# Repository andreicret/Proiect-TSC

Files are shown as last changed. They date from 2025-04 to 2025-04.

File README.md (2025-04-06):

# TSC OpenBook Reader - Alexandru-Andrei CRET

## Project Content

+ **Schematic & PCB Design** → Circuit design files (.sch, .brd)

+ **Manufacturing Files** → Gerber files, Bill of Materials (BOM), and Pick & Place files.

+ **3D Model & Mechanical Design** → Complete 3D assembly of the device, including PCB, battery, display, and enclosure.

+ **Renders & Images** → Visual representations of the final device and PCB layout.

+ **Documentation** → In-depth explanation of hardware architecture, component connections, and design choices.

## Device Diagram

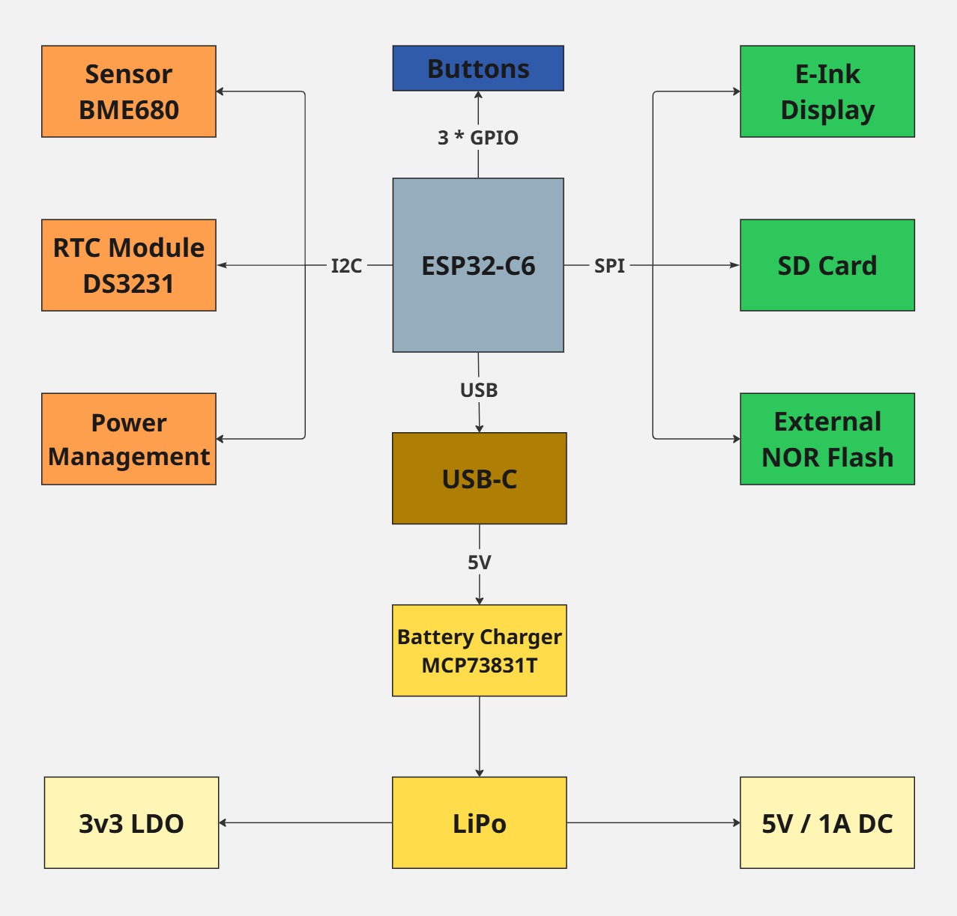
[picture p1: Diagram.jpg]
E-Book Reader Diagram


## Hardware Modules and Components

### ESP32-C6-WROOM-1-N8  (main microcontroller)
- **Key Features:** WiFi 6, Bluetooth 5 LE, RISC-V core
- **Operating Voltage:** 3.3V
- **Communication Interfaces:** SPI, I2C, UART, GPIO

### SD Card Module
- **Interface:** SPI
- **Pin Connections:**
  - `SS_SD` → `IO5`
  - `MOSI` → `IO23`
  - `MISO` → `IO19`
  - `SCK` → `IO18`

### Buttons (User Interface)
- **Interface:** GPIO
- **Pin Connections:**
  - `BUTTON_1` → `IO0` (Used for page turning)
  - `BUTTON_2` → `IO1` (Used for accessing menu options)

### E-Ink Display
- **Interface:** SPI
- **Pin Connections:**
  - `EPD_CS` → `IO15`
  - `EPD_DC` → `IO13`
  - `EPD_RST` → `IO12`
  - `EPD_BUSY` → `IO14`
  - `MOSI`, `SCK` shared with SD card module

### Voltage Regulator (LDO)
- **Purpose:** Converts 5V to 3.3V for powering the ESP32 and other peripherals

### Charging IC (TP4056)
- **Operating Voltage:** 5V via USB-C
- **Function:** Li-Po battery charging and protection

### USB Interface (USB-C Connector)
- **Functionality:** Power and data connection for the device
- **Protection:** ESD protection via TVS diodes

### Li-Po Battery
- **Type:** 3.7V Li-Po
- **Capacity:** 2000mAh

## Communication Interfaces

| **Interface** | **Connected Components** | **ESP32-C6 Pins** |
|---|---|---|
| SPI | E-Ink Display, SD Card | `MOSI` (`IO23`), `MISO` (`IO19`), `SCK` (`IO18`) |
| I2C | (Optional for sensors) | `SDA` (`IO21`), `SCL` (`IO22`) |
| GPIO | Buttons, reset | `IO0`, `IO1` |
| USB | Power and Data (USB-C) | `USB_D+` (`IO14`), `USB_D-` (`IO13`) |

## Estimated Power Consumption

| Component | Average Consumption (mA) |
| :--- | :--- |
| **Typical Total** | **150-250 mA** |
| E-Paper (in refresh) | 20-50 mA |
| SD Card | 30-100 mA |
| DS3231 RTC | 0.2 mA |
| BME688 | 0.8 mA |
| ESP32-C6 (WiFi active) | 80-160 mA |
| External Flash | 10-20 mA |
| ESP32-C6 (idle) | 10 mA |

## Bill of Materials (BOM)

| Component Name | Link | Datasheet |
|---|---|---|
| BD5229G-TR | [Component Search Engine](https://componentsearchengine.com/part-view/BD5229G-TR/ROHM%20Semiconductor) | [Datasheet](https://datasheet.datasheetarchive.com/originals/distributors/Datasheets_SAMA/f2b9741ef86007909f138d561a359946.pdf) |
| ESP32 WROVER 0805 Capacitor | [Mouser](https://ro.mouser.com/ProductDetail/KYOCERA-AVX/SD0805S020S1R0?qs=jCA%252BPfw4LHbpkAoSnwrdjw%3D%3D) | [Datasheet](https://ro.mouser.com/datasheet/2/40/schottky-3165252.pdf) |
| ESP32 WROVER MCP73831 Power Management | [Mouser](https://eu.mouser.com/ProductDetail/Microchip-Technology/MCP73831T-2ACI-OT?qs=yUQqVecv4qvbBQBGbHx0Mw%3D%3D) | [Datasheet](https://eu.mouser.com/datasheet/2/268/MCP73831_Family_Data_Sheet_DS20001984H-3441711.pdf) |
| PGB1010603MR Inductor | [SnapMagic](https://www.snapeda.com/parts/PGB1010603MR/Littelfuse/view-part/?ref=eda) | [Datasheet](https://www.snapeda.com/parts/PGB1010603MR/Littelfuse%20Inc./datasheet/) |
| USBLC6-2SC6Y USB Surge Protection | [SnapMagic](https://www.snapeda.com/parts/USBLC6-2SC6Y/STMicroelectronics/view-part/?ref=eda) | [Datasheet](https://www.snapeda.com/parts/USBLC6-2SC6Y/STMicroelectronics/datasheet/) |
| CPH3225A | [SnapMagic](https://www.snapeda.com/parts/CPH3225A/Seiko+Instruments/view-part/?ref=eda) | [Datasheet](https://www.snapeda.com/parts/CPH3225A/Seiko%20Instruments/datasheet/) |
| Capacitor 0402 | [Component Search Engine](https://componentsearchengine.com/part-view/CC0402MRX5R5BB106/YAGEO) | [Datasheet](https://componentsearchengine.com/Datasheets/2/CC0402MRX5R5BB106.pdf) |
| MAX17048G+T10 Battery Fuel Gauge | [SnapMagic](https://www.snapeda.com/parts/MAX17048G+T10/Analog+Devices/view-part/?ref=eda) | [Datasheet](https://www.snapeda.com/parts/MAX17048G+T10/Analog%20Devices/datasheet/) |
| USB4110-GF-A USB Hub | [Component Search Engine](https://componentsearchengine.com/part-view/USB4110-GF-A/GCT%20(GLOBAL%20CONNECTOR%20TECHNOLOGY)) | [Datasheet](https://gct.co/files/drawings/usb4110.pdf) |
| ESP32-C6 WROOM-1-N8 | [SnapMagic](https://www.snapeda.com/parts/ESP32-C6-WROOM-1-N8/Espressif+Systems/view-part/?ref=eda) | [Datasheet](https://www.snapeda.com/parts/ESP32-C6-WROOM-1-N8/Espressif%20Systems/datasheet/) |
| ESP32 WROVER BME680 Sensor | [SnapMagic](https://www.snapeda.com/parts/BME680/Bosch/view-part/?welcome=home) | [Datasheet](https://www.snapeda.com/parts/BME680/Bosch%20Sensortec/datasheet/) |
| SJ | [GrabCad](https://grabcad.com/library/solder-jumpers-1) | [Datasheet](https://www.youtube.com/watch?v=dQw4w9WgXcQ) |
| RCL CPOL 3528 | [SnapMagic](https://www.snapeda.com/parts/TAJB475K025RNJ/AVX/view-part/?ref=dk&t=capacitor%203528&con_ref=None) | [Datasheet](https://s3.amazonaws.com/snapeda/datasheet/TAJB475K025RNJ_AVX.pdf) |
| ESP32C6 Varistor 1812 | [Mouser](https://ro.mouser.com/ProductDetail/EPCOS-TDK/B72520T0350K062?qs=dEfas%2FXlABIszF52uu7vrg%3D%3D) | [Datasheet](https://www.tdk-electronics.tdk.com/inf/75/db/CTVS_14/Surge_protection_series.pdf) |
| LED Chip 0603 | [SnapMagic](https://www.snapeda.com/parts/KP-1608SURCK/Kingbright/view-part/?ref=search&t=LED%200603) | [Datasheet](https://www.snapeda.com/parts/KP-1608SURCK/Kingbright/datasheet/) |
| DS3231SN RTC | [SnapMagic](https://www.snapeda.com/parts/DS3231SN%23/Analog+Devices/view-part/?ref=eda) | [Datasheet](https://www.snapeda.com/parts/DS3231SN%23/Analog%20Devices/datasheet/) |
| TPTP20R | [Comet](https://easyeda.com/component/7524403feb2642ac9f9f26dfb93ceacf) | [Datasheet](https://easyeda.com/component/7524403feb2642ac9f9f26dfb93ceacf) |
| FH34SRJ-24S-0.5SH Connector | [Component Search Engine](https://componentsearchengine.com/part-view/FH34SRJ-24S-0.5SH(99)/Hirose) | [Datasheet](https://www.hirose.com/en/product/document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) |
| QWIIC Connector | [Mouser](https://eu.mouser.com/ProductDetail/Adafruit/4208?qs=PzGy0jfpSMtbScLbr0L5dw%3D%3D) | [Datasheet](https://www.youtube.com/watch?v=dQw4w9WgXcQ) |
| MBR0530 Schottky Diode | [SnapMagic](https://www.snapeda.com/parts/MBR0530/Onsemi/view-part/?ref=eda) | [Datasheet](https://www.snapeda.com/parts/MBR0530/ON%20Semiconductor/datasheet/) |
| XC6220A331MR-G Voltage Regulator | [Component Search Engine](https://componentsearchengine.com/part-view/XC6220A331MR-G/Torex) | [Datasheet](https://product.torexsemi.com/system/files/series/xc6220.pdf) |
| SI1308EDL-T1-GE3 MOSFET | [SnapMagic](https://www.snapeda.com/parts/SI1308EDL-T1-GE3/Vishay+Siliconix/view-part/?ref=eda) | [Datasheet](https://www.youtube.com/watch?v=dQw4w9WgXcQ) |
| 112A-TAAR-R03 | [Comet](https://store.comet.srl.ro/Catalogue/Product/43497/) | [Datasheet](https://store.comet.bg/download-file.php?id=27596) |
| ESP32 WROVER P-Channel MOSFET | [Component Search Engine](https://componentsearchengine.com/part-view/DMG2305UX-7/Diodes%20Incorporated) | [Datasheet](https://www.diodes.com//assets/Datasheets/DMG2305UX.pdf) |

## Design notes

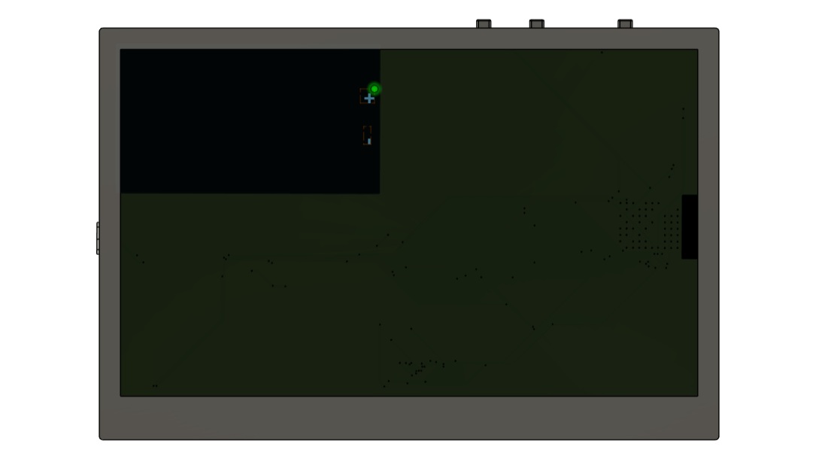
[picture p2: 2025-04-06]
Images/3D_Ebook_bottom.jpg

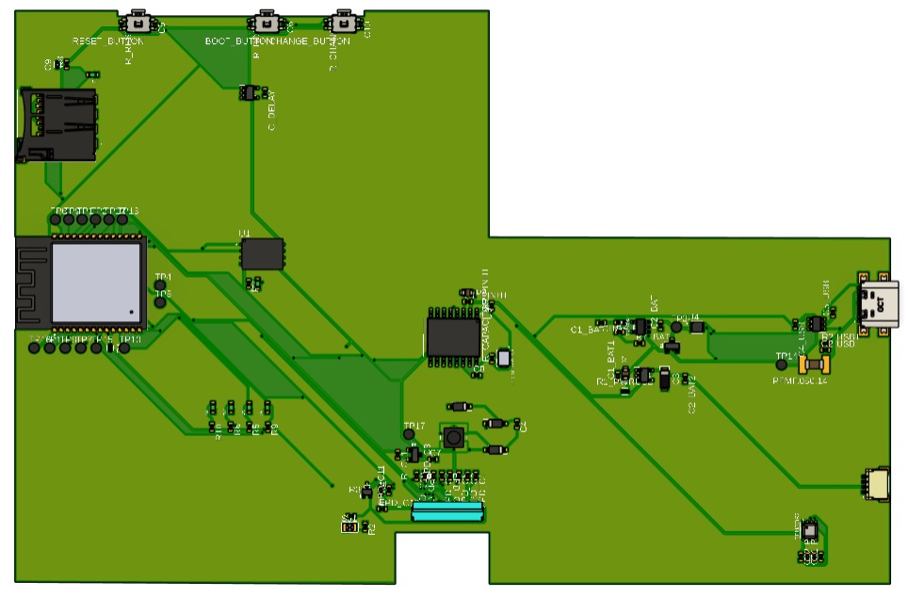
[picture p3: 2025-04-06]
Images/3D-Top.jpg

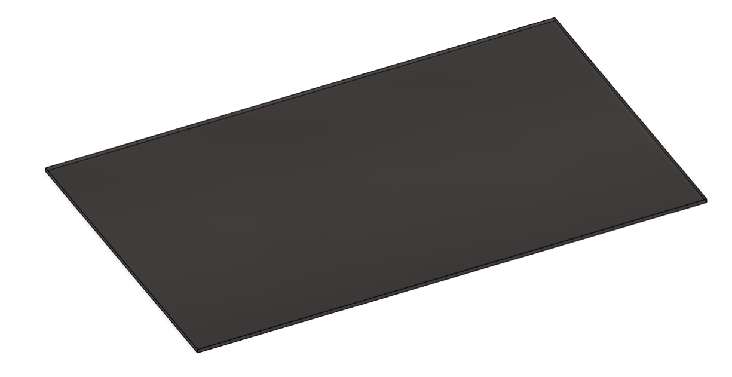
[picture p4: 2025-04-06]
Images/3D_Display.jpg

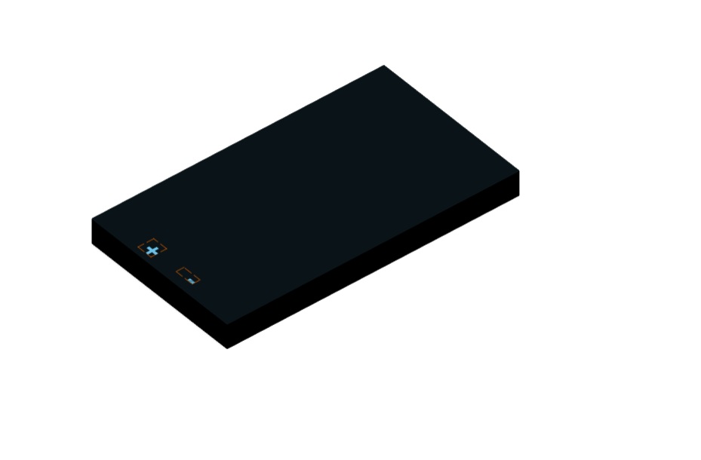
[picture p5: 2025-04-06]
Images/3D_Battery.jpg

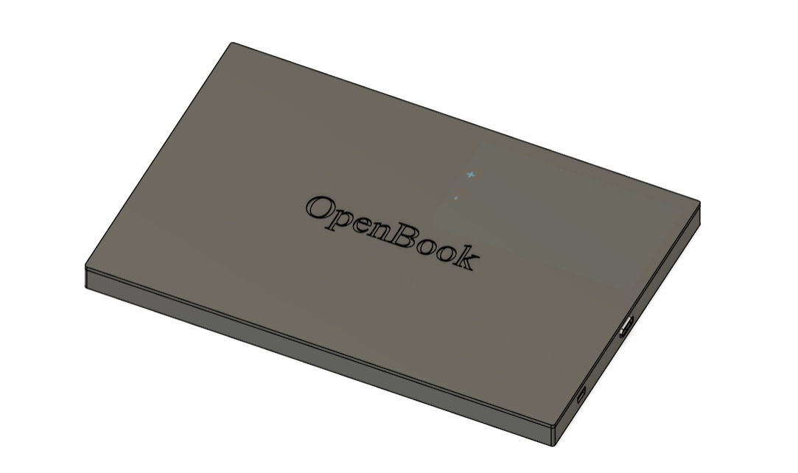
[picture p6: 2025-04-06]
Images/3D_Ebook.jpg

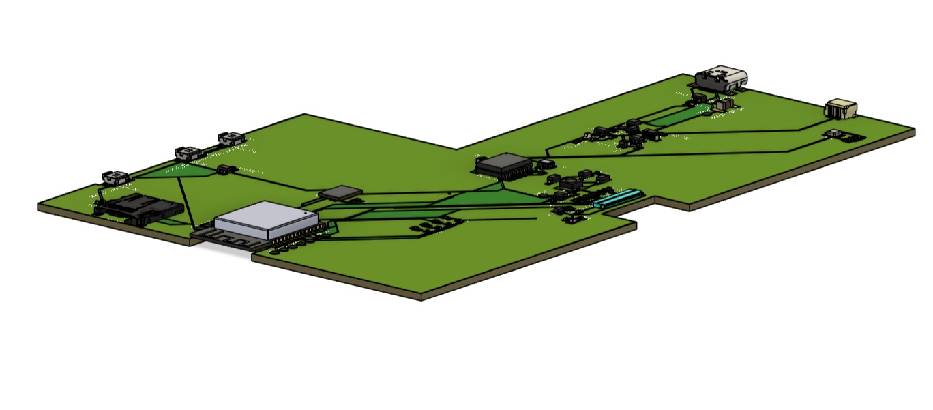
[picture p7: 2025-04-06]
Images/Side_3D.jpg

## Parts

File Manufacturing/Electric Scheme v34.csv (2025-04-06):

Qty | Value | Device | Package | Parts | Description | ARROW_PART_NUMBER | ARROW_PRICE-STOCK | AVAILABILITY | CATEGORY | CHECK_PRICES | COPYRIGHT | DESCRIPTION | ETC | HEIGHT | MANUFACTURER | MANUFACTURER_NAME | MANUFACTURER_PART_NUMBER | MF | MFR_NAME | MOUSER_PART_NUMBER | MOUSER_PRICE-STOCK | MOUSER_TESTING_PART_NUMBER | MOUSER_TESTING_PRICE-STOCK | MP | MPN | OPERATING_TEMP | PACKAGE | PART_STATUS | POPULARITY | PRICE | PROD_ID | PURCHASE-URL | RATING | ROHS_COMPLIANT | SERIES | SNAPEDA_LINK | SUB-CATEGORY | THERMALLOSS | TOLERANCE | TYPE | VALUE | VOLTAGE_RATING
1 |  | ADAFRUIT_LEDCHIP-LED0603 | ADAFRUIT_CHIP-LED0603 | CHG_LED | LED
1 |  | SJ | SJ | SJ1 | SMD solder JUMPER |  |  |  |  |  |  |  |  |  |  |  |  |  |  |  |  |  |  |  |  |  |  |  | 3
1 | 0.1uF/50V | EAGLE-LTSPICE_C | EAGLE-LTSPICE_C0402 | EPD_C5 | CAPACITOR, European symbol
1 | 0.47 | ESP32_WROVER_EAGLE-LTSPICE_R | ESP32_WROVER_EAGLE-LTSPICE_R0402 | R3 | RESISTOR, European symbol
1 | 100K | RESISTOR__CHIP-0402(1005-METRIC) | RESC1005X40 | R1_PWRUSB | Resistor Fixed - Generic |  |  |  | Resistor |  |  |  |  |  |  |  |  |  |  |  |  |  |  |  |  |  |  |  |  |  |  |  |  |  |  |  | Fixed
1 | 100Nf | ESP32_WROVER_EAGLE-LTSPICE_C | ESP32_WROVER_EAGLE-LTSPICE_C0402 | C8 | CAPACITOR, European symbol
1 | 100Uf_TANT | CAPACITOR-POL_TANTALUM-1206(3216-METRIC) | CAPMP3216X180N | C3 | Capacitor Polarised - Generic |  |  |  | Capacitor
1 | 100nF | CAPACITOR_CHIP-0402(1005-METRIC) | CAPC1005X60 | C9 | Capacitor - Generic |  |  |  | Capacitor
6 | 100nF | EAGLE-LTSPICE_C | EAGLE-LTSPICE_C0402 | C1, C2, C4_USB, C6, C10, C_DELAY | CAPACITOR, European symbol
15 | 10K | ESP32_WROVER_EAGLE-LTSPICE_R | ESP32_WROVER_EAGLE-LTSPICE_R0402 | R1-PINH, R1_PINH1, R2-PINH, R2-PINH1, R4, R5, R6, R7, R8, R9, R10, R_BOOT, R_CHANGE, R_CL1, R_RESET | RESISTOR, European symbol
1 | 10K | RESISTOR__CHIP-0402(1005-METRIC) | RESC1005X40 | R1 | Resistor Fixed - Generic |  |  |  | Resistor |  |  |  |  |  |  |  |  |  |  |  |  |  |  |  |  |  |  |  |  |  |  |  |  |  |  |  | Fixed
1 | 10uF | EAGLE-LTSPICE_C | EAGLE-LTSPICE_C0402 | C7 | CAPACITOR, European symbol
1 | 112A-TAAR-R03_ATTEND | 112A-TAAR-R03_ATTEND | 112ATAARR03ATTEND | J4 | Micro SD Card Socket, Push-Push Type, Top Mount, SMT, H=1.83mm, 10u |  |  |  |  |  |  | Micro SD Card Socket | Push-Push Type | Top Mount | SMT | H=1.83mm | 10u |  | 1.9mm |  | ATTEND | 112A-TAAR-R03 ATTEND
1 | 15 | ESP32_WROVER_EAGLE-LTSPICE_R | ESP32_WROVER_EAGLE-LTSPICE_R0402 | R_CAPACITOR | RESISTOR, European symbol
1 | 1uF | EAGLE-LTSPICE_C | EAGLE-LTSPICE_C0402 | C5 | CAPACITOR, European symbol
7 | 1uF/50V | EAGLE-LTSPICE_C | EAGLE-LTSPICE_C0402 | EPD_C6, EPD_C7, EPD_C8, EPD_C9, EPD_C10, EPD_C11, EPD_C12 | CAPACITOR, European symbol
2 | 1uF/50V | ESP32_WROVER_EAGLE-LTSPICE_C | ESP32_WROVER_EAGLE-LTSPICE_C0402 | EPD_C1, EPD_C2 | CAPACITOR, European symbol
1 | 2.2 | ESP32_WROVER_EAGLE-LTSPICE_R | ESP32_WROVER_EAGLE-LTSPICE_R0402 | R2 | RESISTOR, European symbol
1 | 200 | ESP32_WROVER_EAGLE-LTSPICE_R | ESP32_WROVER_EAGLE-LTSPICE_R0402 | R1_BAT | RESISTOR, European symbol
2 | 20V/4.2A/52mO/1.4W | ESP32_WROVER_SPARKFUN-DISCRETESEMI_MOSFET_PCH-DMG2305UX-7 | ESP32_WROVER_SPARKFUN-DISCRETESEMI_SOT23-3 | Q1, Q2 | P-channel MOSFETs |  |  |  |  |  |  |  |  |  |  |  |  |  |  |  |  |  |  |  |  |  |  |  |  |  | TRAN-14388 |  |  |  |  |  |  |  |  |  | 20V/4.2A/52mO/1.4W
1 | 2K | ESP32_WROVER_EAGLE-LTSPICE_R | ESP32_WROVER_EAGLE-LTSPICE_R0402 | R2_BAT | RESISTOR, European symbol
1 | 4.7Uf | EAGLE-LTSPICE_C | EAGLE-LTSPICE_C0402 | C5_USB | CAPACITOR, European symbol
4 | 4.7uF | EAGLE-LTSPICE_C | EAGLE-LTSPICE_C0402 | C1_BAT, C1_BAT1, C2_BAT, C2_BAT2 | CAPACITOR, European symbol
1 | 4.7uF/25V | EAGLE-LTSPICE_C | EAGLE-LTSPICE_C0402 | C4 | CAPACITOR, European symbol
1 | 5K1 | ESP32_WROVER_EAGLE-LTSPICE_R | ESP32_WROVER_EAGLE-LTSPICE_R0402 | R2-USB1 | RESISTOR, European symbol
1 | 5k1 | ESP32_WROVER_EAGLE-LTSPICE_R | ESP32_WROVER_EAGLE-LTSPICE_R0402 | R2-USB | RESISTOR, European symbol
1 | 744043680IND_4828-WE-TPC_WRE | 744043680IND_4828-WE-TPC_WRE | IND_4828-WE-TPC_WRE | L1 |  |  |  |  |  |  | Copyright (C) 2024 Ultra Librarian. All rights reserved. |  | 68uH |  |  |  | 744043680 |  | Wurth Electronics
1 | BD5229G-TR | BD5229G-TR | SOT95P280X125-5N | IC1 | Voltage Detector with Adjustable Delay Time: CMOS processes are utilized to develop high precision, low current consumption CMOS reset ICs that allow arbitrary setting of the delay time. The extensive lineup includes both Nch Open Drain and CMOS output types in a wide range of detection voltages (from 2.3V to 6.0V, in 0.1V steps), enabling selection of the ideal solution based on customer requirements. In addition, the entire series is of course both lead-free and RoHS-compliant. |  |  |  |  |  |  | Voltage Detector with Adjustable Delay Time: CMOS processes are utilized to develop high precision | low current consumption CMOS reset ICs that allow arbitrary setting of the delay time. The extensive lineup includes both Nch Open Drain and CMOS output types in a wide range of detection voltages (from 2.3V to 6.0V | in 0.1V steps) | enabling selection of the ideal solution based on customer requirements. In addition | the entire series is of course both lead-free and RoHS-compliant. |  | 1.25mm |  | ROHM Semiconductor | BD5229G-TR |  |  | 755-BD5229G-TR | https://www.mouser.co.uk/ProductDetail/ROHM-Semiconductor/BD5229G-TR?qs=4kLU8WoGk0vvnhrrYwdszw%3D%3D
1 | BME688 | ESP32_WROVER_BME680_BME680 | ESP32_WROVER_BME680_PSON80P300X300X100-8N | SENSOR2 | Integrated Environmental Unit |  |  | Unavailable |  |  |  | Integrated Environmental Unit |  |  |  |  |  | Bosch Sensortec |  |  |  |  |  | BME680 |  |  | LGA-8 Bosch Tools |  |  | None
3 | BUTTON_CUSYOMV1BUTTON | BUTTON_CUSYOMV1BUTTON | MYBUTTON | BOOT_BUTTON, CHANGE_BUTTON, RESET_BUTTON
1 | CPH3225A | CPH3225A | CAPCP3225X100N | C10_SUPERCAP | Cap 0.011F 3.3V 1210 Flat Check availability |  |  | Not in stock |  | https://www.snapeda.com/parts/CPH3225A/Seiko+Instruments/view-part/?ref=eda |  | 11 mF (EDLC) Supercapacitor 3.3 V 1210 (3225 Metric) - - |  |  |  |  |  | Seiko Instruments |  |  |  |  |  | CPH3225A |  |  | 1210 Seiko |  |  | None |  | https://www.snapeda.com/api/url_track_click_mouser/?unipart_id=562593&manufacturer=Seiko Instruments&part_name=CPH3225A&search_term=None |  |  |  | https://www.snapeda.com/parts/CPH3225A/Seiko+Instruments/view-part/?ref=snap
1 | DS3231SN# | DS3231SN# | SOIC127P1032X265-16N | U3 | Real Time Clock Serial 16-Pin SOIC W T/R Check availability |  |  | In Stock |  | https://www.snapeda.com/parts/DS3231SN%23/Analog+Devices/view-part/?ref=eda |  | Extremely Accurate I²C-Integrated RTC/TCXO/Crystal |  |  |  |  |  | Analog Devices |  |  |  |  |  | DS3231SN# |  |  | SOIC-16 Maxim |  |  | None |  | https://www.snapeda.com/api/url_track_click_mouser/?unipart_id=99048&manufacturer=Analog Devices&part_name=DS3231SN#&search_term=None |  |  |  | https://www.snapeda.com/parts/DS3231SN%23/Analog+Devices/view-part/?ref=snap
1 | ESP32-C6-WROOM-1-N8 | ESP32-C6-WROOM-1-N8 | XCVR_ESP32-C6-WROOM-1-N8 | U2 | Check availability |  |  | In Stock |  | https://www.snapeda.com/parts/ESP32-C6-WROOM-1-N8/Espressif+Systems/view-part/?ref=eda |  | Multiprotocol Modules ESP32-C6 module | Wi-Fi 6 in 2.4 GHz band | Bluetooth 5 | Zigbee 3.0 and Thread. ESP34-WROOM Compatible - ENGINEERING SAMPLE |  |  |  |  |  | Espressif Systems |  |  |  |  |  | ESP32-C6-WROOM-1-N8 |  |  | None |  |  | None |  |  |  |  |  | https://www.snapeda.com/parts/ESP32-C6-WROOM-1-N8/Espressif+Systems/view-part/?ref=snap
1 | ESP32C6_VARISTORCN1812 | ESP32C6_VARISTORCN1812 | ESP32C6_VARISTOR_CT/CN1812 | PFMF.050.14 | VARISTOR |  |  |  |  |  |  |  |  |  |  |  |  |  |  |  |  |  |  |  |  |  |  |  | 0
2 | ESP32_WROVER_AVX---SD0805S020S1R0_AVX_SD0805S020S1R0_0_0 | ESP32_WROVER_AVX---SD0805S020S1R0_AVX_SD0805S020S1R0_0_0 | ESP32_WROVER_AVX---SD0805S020S1R0_AVX_SD0805S020S1R0_0 | D2, D7 | Schottky Barrier Rectifier Diode
1 | ESP32_WROVER_SPARKFUN-IC-POWER_MCP73831 | ESP32_WROVER_SPARKFUN-IC-POWER_MCP73831 | ESP32_WROVER_SPARKFUN-IC-POWER_SOT23-5 | MCP73831 | MCP73831T Li-Ion, Li-Pol Controller |  |  |  |  |  |  |  |  |  |  |  |  |  |  |  |  |  |  |  |  |  |  |  |  |  | IC-09995
1 | FH34SRJ-24S-0.5SH_99_ | FH34SRJ-24S-0.5SH_99_ | FH34SRJ24S05SH99 | J1 | (0.50mm) Surface Mount, Right Angle |  |  |  |  |  |  | 24 Position FFC | FPC Connector Contacts | (0.50mm) Surface Mount | Right Angle |  | 1.1mm |  | Hirose | FH34SRJ-24S-0.5SH(99) |  |  | 798-FH34SRJ24S05SH99 | https://www.mouser.co.uk/ProductDetail/Hirose-Connector/FH34SRJ-24S-0.5SH99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
1 | MAX17048G+T10 | MAX17048G+T10 | SON50P200X200X80-9N | U4 | Check availability |  |  | In Stock |  | https://www.snapeda.com/parts/MAX17048G+T10/Analog+Devices/view-part/?ref=eda |  | 3µA 1-Cell/2-Cell Fuel Gauge with ModelGauge |  |  |  |  |  | Analog Devices |  |  |  |  |  | MAX17048G+T10 |  |  | TDFN-8 Maxim |  |  | None |  | https://www.snapeda.com/api/url_track_click_mouser/?unipart_id=329239&manufacturer=Analog Devices&part_name=MAX17048G+T10&search_term=None |  |  |  | https://www.snapeda.com/parts/MAX17048G+T10/Analog+Devices/view-part/?ref=snap
3 | MBR0530 | MBR0530 | SOD3716X135N | D3, D4, D5 | ON SEMICONDUCTOR - MBR0530 - DIODE, SCHOTTKY, 0.5A, 30V, SOD-123
6 | PGB1010603MRDIOCDIODE | PGB1010603MRDIOCDIODE | DIOC1608X36N | D6, D8, D9, D10, D11, D12 | Check availability
1 | QWIIC_RIGHT_ANGLE | QWIIC_CONNECTORJS-1MM | JST04_1MM_RA | J3 | SparkFun I2C Standard Qwiic Connector |  |  |  |  |  |  |  |  |  |  |  |  |  |  |  |  |  |  |  |  |  |  |  |  |  | CONN-13694 |  |  |  |  |  |  |  |  |  | QWIIC_RIGHT_ANGLE
1 | SAMACSYS_PARTS_USB4110-GF-A | SAMACSYS_PARTS_USB4110-GF-A | SAMACSYS_PARTS_USB4110GFA | J2 | CONN USB 2.0 TYPE-C R/A SMT |  |  |  |  |  |  | CONN USB 2.0 TYPE-C R/A SMT |  | 3.26mm |  | GCT (GLOBAL CONNECTOR TECHNOLOGY) | USB4110-GF-A |  |  | 640-USB4110-GF-A | https://www.mouser.co.uk/ProductDetail/GCT/USB4110-GF-A?qs=KUoIvG%2F9IlYiZvIXQjyJeA%3D%3D
1 | SI1308EDL-T1-GE3 | SI1308EDL-T1-GE3 | SOT65P210X110-3N | Q3 | MOSFET N-Ch 30V 1.5A TrenchFET SC70 Vishay Si1308EDL-T1-GE3 N-channel MOSFET Transistor, 1.5 A, 30 V, 3-Pin SC-70 |  |  | In Stock |  | https://www.snapeda.com/parts/SI1308EDL-T1-GE3/Vishay+Siliconix/view-part/?ref=eda |  | Si1308EDL-T1-GE3 N-channel MOSFET Transistor | 1.5 A | 30 V | 3-Pin SC-70 | Siliconix / Vishay SI1308EDL-T1-GE3 |  |  |  |  |  | Vishay Siliconix |  |  |  |  |  | SI1308EDL-T1-GE3 |  |  | SOT-323 Vishay Semiconductor |  |  | None |  | https://www.snapeda.com/api/url_track_click_mouser/?unipart_id=274603&manufacturer=Vishay Siliconix&part_name=SI1308EDL-T1-GE3&search_term=None |  |  |  | https://www.snapeda.com/parts/SI1308EDL-T1-GE3/Vishay+Siliconix/view-part/?ref=snap
17 | TP | TP | TP20R | TP1, TP2, TP3, TP4, TP5, TP6, TP7, TP8, TP9, TP10, TP11, TP12, TP13, TP14, TP15, TP16, TP17 | Test pad
1 | USBLC6-2SC6Y | USBLC6-2SC6Y | SOT95P280X145-6N | D1 | Low Cap. ESD Protection Auto SOT-23-6 STMicroelectronics USBLC6-2SC6Y, Dual Uni-Directional TVS Diode Array, 6-Pin SOT-23 |  |  | In Stock |  | https://www.snapeda.com/parts/USBLC6-2SC6Y/STMicroelectronics/view-part/?ref=eda |  | 17V Clamp 5A (8/20µs) Ipp Tvs Diode Surface Mount SOT-23-6 |  |  |  |  |  | STMicroelectronics |  |  |  |  |  | USBLC6-2SC6Y |  |  | SOT-23-6 STMicroelectronics |  |  | None |  |  |  |  |  | https://www.snapeda.com/parts/USBLC6-2SC6Y/STMicroelectronics/view-part/?ref=snap
1 | W25Q512JVEIQ | W25Q512JVEIQ | SON127P600X800X80-9N | U1 | Check availability |  |  | In Stock |  | https://www.snapeda.com/parts/W25Q512JVEIQ/Winbond+Electronics/view-part/?ref=eda |  | FLASH - NOR Memory IC 512Mb (64M x 8) SPI - Quad I/O 133 MHz 8-WSON (8x6) |  |  |  |  |  | Winbond Electronics |  |  |  |  |  | W25Q512JVEIQ |  |  | Package |  |  | None |  |  |  |  |  | https://www.snapeda.com/parts/W25Q512JVEIQ/Winbond+Electronics/view-part/?ref=snap
1 | XC6220A331MR-G | XC6220A331MR-G | SOT95P280X120-5N | IC4 | LDO Voltage Regulators |  |  |  |  |  |  | LDO Voltage Regulators |  | 1.2mm |  | Torex | XC6220A331MR-G |  |  | 865-XC6220A331MR-G | https://www.mouser.co.uk/ProductDetail/Torex-Semiconductor/XC6220A331MR-G?qs=AsjdqWjXhJ8ZSWznL1J0gg%3D%3D

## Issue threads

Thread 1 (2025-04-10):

erori / warninguri nerezolvate ERC

StoicaRares634, 2025-04-10:
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

„Segment of net PREVGL has fallen apart” -> Inseamna necontinuitate in conexiunea electrica, ceea ce va duce la nefunctionare. Verifica toate punctele din schema unde apare label-ul PREVGL.

„SUPPLY pin GND overwritten with more than one signal” -> Indica faptul ca pinul de alimentare GND este conectat la mai multe retele diferite, ceea ce nu este permis. Verifica toate conexiunile facute la GND in schema.

La warninguri -> verifica din nou conexiunile facute

andreicret, 2025-04-13:
Într-adevăr, am omis niște fire pentru niște conexiuni în aer, am dat valori LED-ului și frame-ului și am mutat label-urile PREVGL și PREVGH pentru display header.

Closed 2025-04-13.

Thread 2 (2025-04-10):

Slikscreen greu de citit

StoicaRares634, 2025-04-10:
Incearca sa muti numele si valorile componentelor pentru a fi mai usor de citit

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

andreicret, 2025-04-14:
Updated so that the PCB is completely clean. Other labels have been moved on PCB.

Closed 2025-04-14.

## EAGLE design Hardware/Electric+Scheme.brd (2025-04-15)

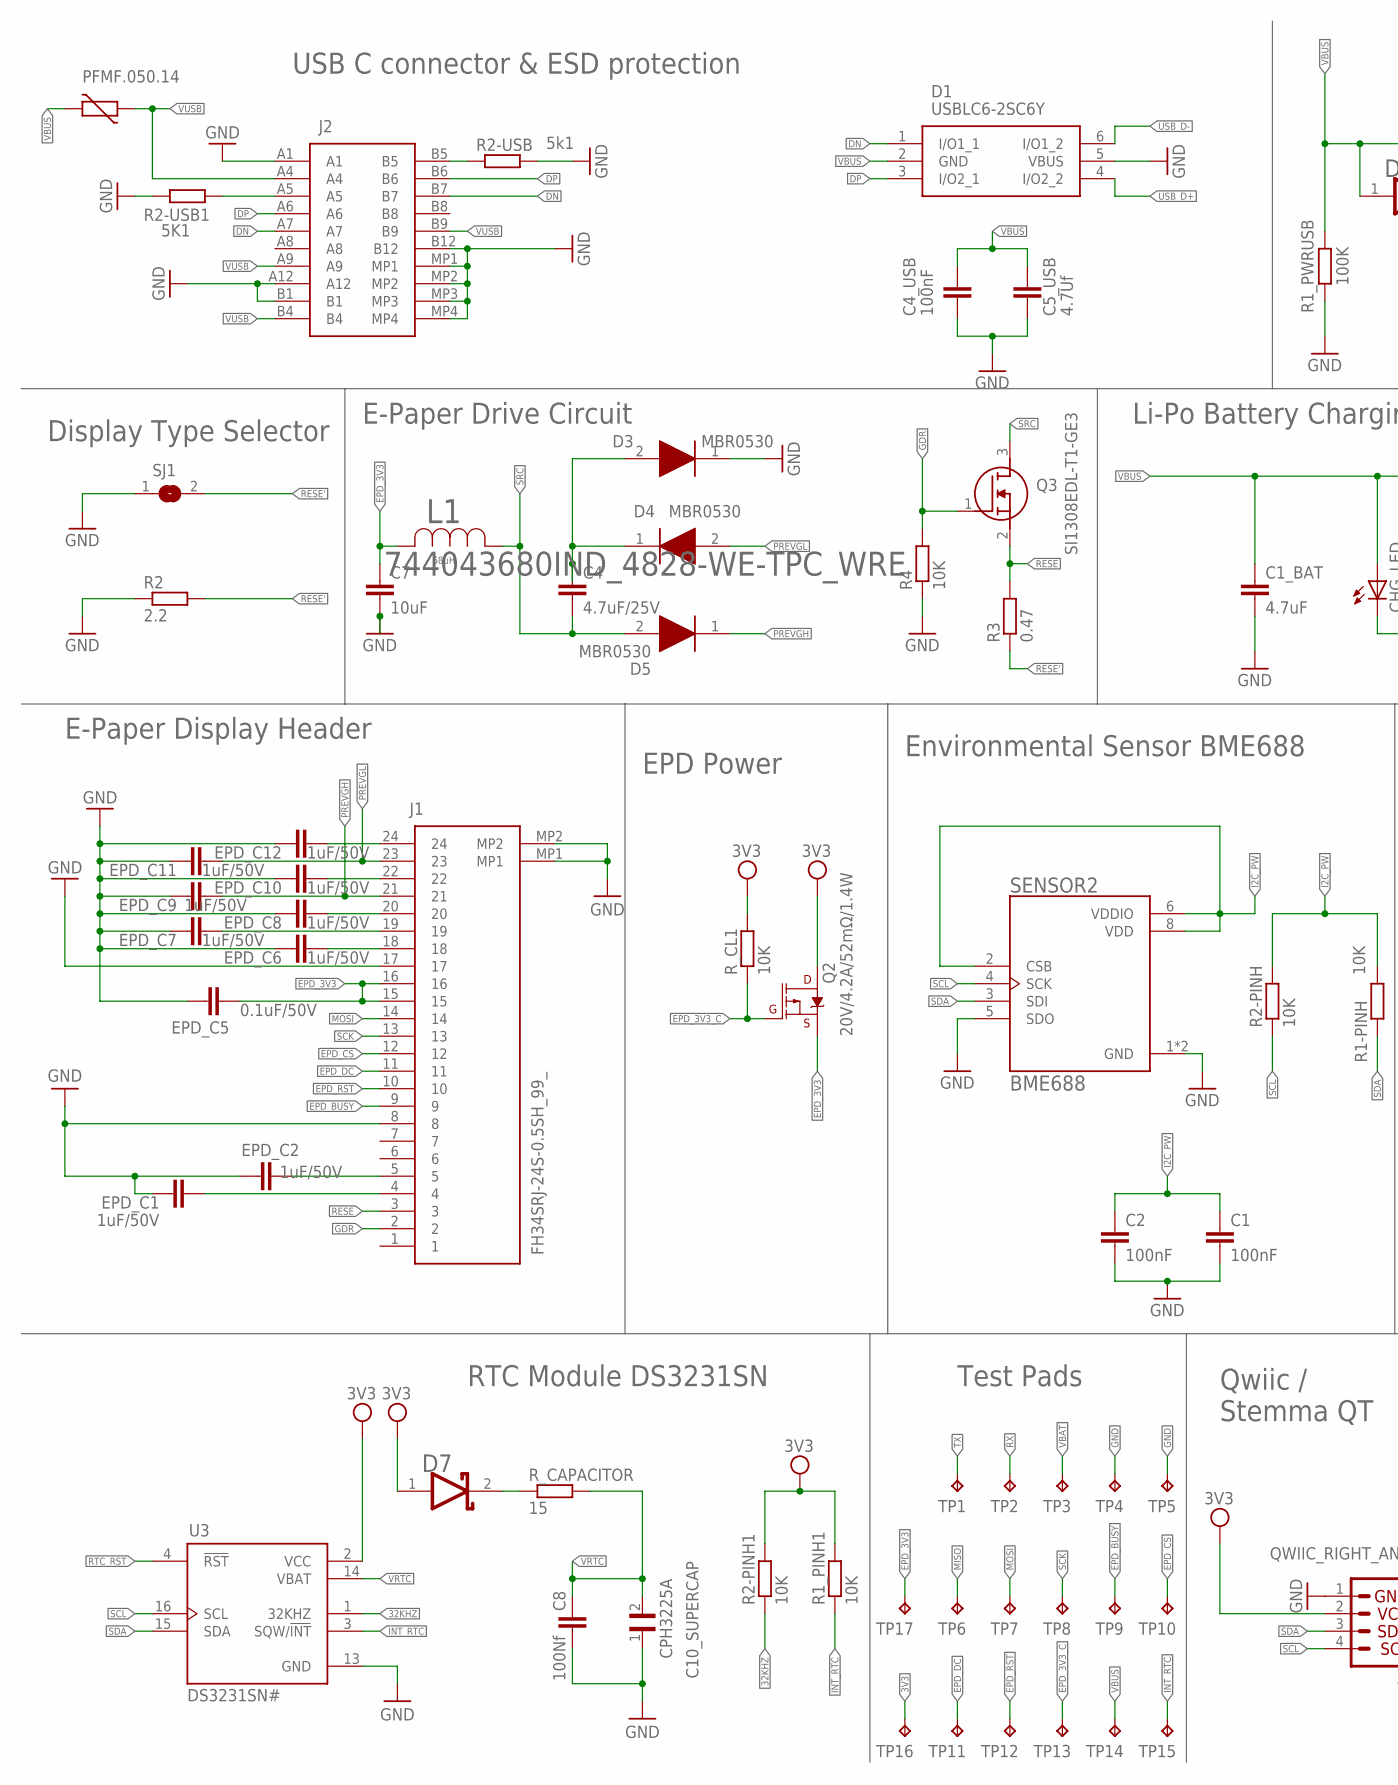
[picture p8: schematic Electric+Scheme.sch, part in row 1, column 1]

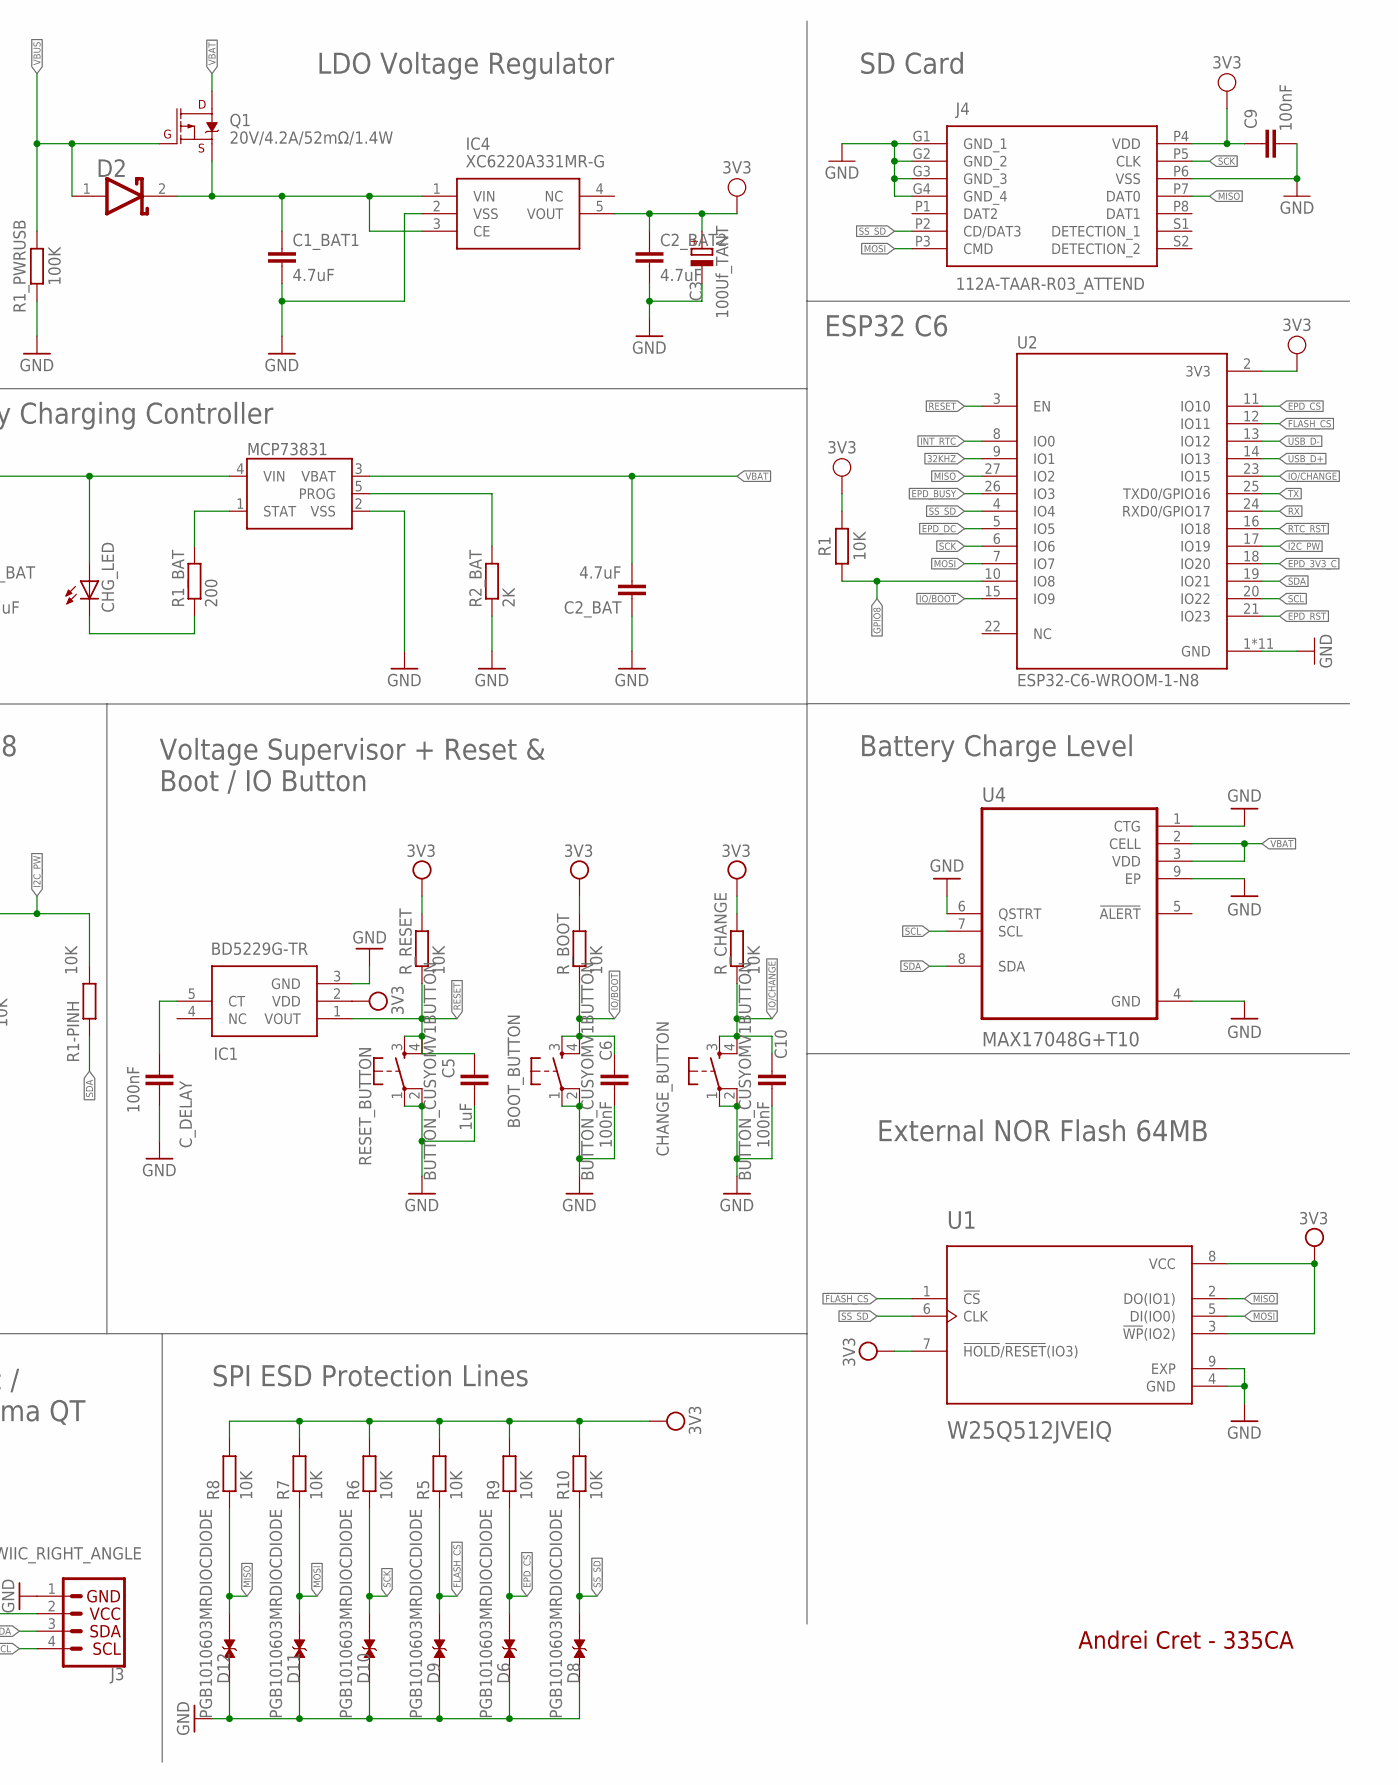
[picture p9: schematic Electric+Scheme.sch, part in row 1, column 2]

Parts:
BOOT_BUTTON: BUTTON_CUSYOMV1BUTTON; MYBUTTON
C1, C2, C4_USB, C6, C10: 100nF; EAGLE-LTSPICE_C0402
C1_BAT, C1_BAT1, C2_BAT, C2_BAT2: 4.7uF; EAGLE-LTSPICE_C0402
C3: 100Uf_TANT; CAPMP3216X180N
C4: 4.7uF/25V; EAGLE-LTSPICE_C0402
C5: 1uF; EAGLE-LTSPICE_C0402
C5_USB: 4.7Uf; EAGLE-LTSPICE_C0402
C7: 10uF; EAGLE-LTSPICE_C0402
C8: 100Nf; ESP32_WROVER_EAGLE-LTSPICE_C0402
C9: 100nF; CAPC1005X60
C10_SUPERCAP: CPH3225A; CAPCP3225X100N
CHANGE_BUTTON: BUTTON_CUSYOMV1BUTTON; MYBUTTON
CHG_LED: RED; ADAFRUIT_CHIP-LED0603
C_DELAY: 100nF; EAGLE-LTSPICE_C0402
D1: USBLC6-2SC6Y; SOT95P280X145-6N
D2, D7: ESP32_WROVER_AVX---SD0805S020S1R0_AVX_SD0805S020S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; ESP32_WROVER_AVX---SD0805S020S1R0_AVX_SD0805S020S1R0_0
D3, D4, D5: MBR0530; SOD3716X135N
D6, D8, D9, D10, D11, D12: PGB1010603MRDIOCDIODE; DIOC1608X36N
EPD_C1, EPD_C2: 1uF/50V; ESP32_WROVER_EAGLE-LTSPICE_C0402
EPD_C5: 0.1uF/50V; EAGLE-LTSPICE_C0402
EPD_C6, EPD_C7, EPD_C8, EPD_C9, EPD_C10, EPD_C11, EPD_C12: 1uF/50V; EAGLE-LTSPICE_C0402
IC1: BD5229G-TR; SOT95P280X125-5N
IC4: XC6220A331MR-G; SOT95P280X120-5N
J1: FH34SRJ-24S-0.5SH_99_; FH34SRJ24S05SH99
J2: SAMACSYS_PARTS_USB4110-GF-A; SAMACSYS_PARTS_USB4110GFA
J3: QWIIC_RIGHT_ANGLE; JST04_1MM_RA
J4: 112A-TAAR-R03_ATTEND; 112ATAARR03ATTEND
L1: 744043680IND_4828-WE-TPC_WRE; IND_4828-WE-TPC_WRE
MCP73831: ESP32_WROVER_SPARKFUN-IC-POWER_MCP73831; ESP32_WROVER_SPARKFUN-IC-POWER_SOT23-5
PFMF.050.14: ESP32C6_VARISTORCN1812; ESP32C6_VARISTOR_CT/CN1812
Q1, Q2: 20V/4.2A/52mΩ/1.4W; ESP32_WROVER_SPARKFUN-DISCRETESEMI_SOT23-3
Q3: SI1308EDL-T1-GE3; SOT65P210X110-3N
R1: 10K; RESC1005X40
R1-PINH, R1_PINH1, R2-PINH, R2-PINH1, R4, R5, R6, R7, R8, R9, R10: 10K; ESP32_WROVER_EAGLE-LTSPICE_R0402
R1_BAT: 200; ESP32_WROVER_EAGLE-LTSPICE_R0402
R1_PWRUSB: 100K; RESC1005X40
R2: 2.2; ESP32_WROVER_EAGLE-LTSPICE_R0402
R2-USB: 5k1; ESP32_WROVER_EAGLE-LTSPICE_R0402
R2-USB1: 5K1; ESP32_WROVER_EAGLE-LTSPICE_R0402
R2_BAT: 2K; ESP32_WROVER_EAGLE-LTSPICE_R0402
R3: 0.47; ESP32_WROVER_EAGLE-LTSPICE_R0402
RESET_BUTTON: BUTTON_CUSYOMV1BUTTON; MYBUTTON
R_BOOT: 10K; ESP32_WROVER_EAGLE-LTSPICE_R0402
R_CAPACITOR: 15; ESP32_WROVER_EAGLE-LTSPICE_R0402
R_CHANGE: 10K; ESP32_WROVER_EAGLE-LTSPICE_R0402
R_CL1: 10K; ESP32_WROVER_EAGLE-LTSPICE_R0402
R_RESET: 10K; ESP32_WROVER_EAGLE-LTSPICE_R0402
SENSOR2: BME688; ESP32_WROVER_BME680_PSON80P300X300X100-8N
SJ1: SOLDERJUMPER; SJ
TP1, TP2, TP3, TP4, TP5, TP6, TP7, TP8, TP9, TP10, TP11, TP12, TP13, TP14, TP15, TP16, TP17: TP; TP20R
U1: W25Q512JVEIQ; SON127P600X800X80-9N
U2: ESP32-C6-WROOM-1-N8; XCVR_ESP32-C6-WROOM-1-N8
U3: DS3231SN#; SOIC127P1032X265-16N
U4: MAX17048G+T10; SON50P200X200X80-9N

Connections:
3V3: C2_BAT2.1, C3.1 (+), C9.2, D7.1 (ANODE), IC1.2 (VDD), IC4.5 (VOUT), J3.2, J4.P4 (VDD), Q2.3 (D), R1.2, R1_PINH1.2, R2-PINH1.2, R5.2, R6.2, R7.2, R8.2, R9.2, R10.2, R_BOOT.2, R_CHANGE.2, R_CL1.2, R_RESET.2, TP16.TP, U1.3 (!WP!(IO2)), U1.7 (!HOLD!/!RESET!(IO3)), U1.8 (VCC), U2.2 (3V3), U3.2 (VCC)
32KHZ: R2-PINH1.1, U2.9 (IO1), U3.1 (32KHZ)
DN: D1.1 (I/O1_1), J2.A7, J2.B7
DP: D1.3 (I/O2_1), J2.A6, J2.B6
EPD_3V3: C7.1, EPD_C5.2, J1.15, J1.16, L1.2, Q2.2 (S), TP17.TP
EPD_3V3_C: Q2.1 (G), R_CL1.1, TP13.TP, U2.18 (IO20)
EPD_BUSY: J1.9, TP9.TP, U2.26 (IO3)
EPD_CS: D6.2, J1.12, R9.1, TP10.TP, U2.11 (IO10)
EPD_DC: J1.11, TP11.TP, U2.5 (IO5)
EPD_RST: J1.10, TP12.TP, U2.21 (IO23)
FLASH_CS: D9.2, R5.1, U1.1 (!CS), U2.12 (IO11)
GDR: J1.2, Q3.1 (G), R4.2
GND: BOOT_BUTTON.1, BOOT_BUTTON.2, C1.2, C1_BAT.2, C1_BAT1.2, C2.2, C2_BAT.1, C2_BAT2.2, C3.2 (-), C4_USB.2, C5.2, C5_USB.2, C6.2, C7.2, C8.2, C9.1, C10.2, C10_SUPERCAP.1, CHANGE_BUTTON.1, CHANGE_BUTTON.2, C_DELAY.2, D1.5 (VBUS), D3.1 (K), D6.1, D8.1, D9.1, D10.1, D11.1, D12.1, EPD_C1.1, EPD_C2.1, EPD_C5.1, EPD_C6.1, EPD_C7.1, EPD_C8.1, EPD_C9.1, EPD_C10.1, EPD_C11.1, EPD_C12.1, IC1.3 (GND), IC4.2 (VSS), J1.8, J1.17, J1.MP1, J1.MP2, J2.A1, J2.A12, J2.B1, J2.B12, J2.MP1, J2.MP2, J2.MP3, J2.MP4, J3.1, J4.G1 (GND_1), J4.G2 (GND_2), J4.G3 (GND_3), J4.G4 (GND_4), J4.P6 (VSS), MCP73831.2 (VSS), R1_PWRUSB.1, R2.1, R2-USB.2, R2-USB1.1, R2_BAT.1, R4.1, RESET_BUTTON.1, RESET_BUTTON.2, SENSOR2.1 (GND), SENSOR2.5 (SDO), SENSOR2.7 (GND), SJ1.1, TP4.TP, TP5.TP, U1.4 (GND), U1.9 (EXP), U2.1 (GND), U2.28 (GND), U2.29_1 (GND), U2.29_2 (GND), U2.29_3 (GND), U2.29_4 (GND), U2.29_5 (GND), U2.29_6 (GND), U2.29_7 (GND), U2.29_8 (GND), U2.29_9 (GND), U3.13 (GND), U4.1 (CTG), U4.4 (GND), U4.6 (QSTRT), U4.9 (EP)
GPIO8: R1.1, U2.10 (IO8)
I2C_PW: C1.1, C2.1, R1-PINH.2, R2-PINH.2, SENSOR2.2 (CSB), SENSOR2.6 (VDDIO), SENSOR2.8 (VDD), U2.17 (IO19)
INT_RTC: R1_PINH1.1, TP15.TP, U2.8 (IO0), U3.3 (SQW/!INT)
IO/BOOT: BOOT_BUTTON.3, BOOT_BUTTON.4, C6.1, R_BOOT.1, U2.15 (IO9)
IO/CHANGE: C10.1, CHANGE_BUTTON.3, CHANGE_BUTTON.4, R_CHANGE.1, U2.23 (IO15)
MISO: D12.2, J4.P7 (DAT0), R8.1, TP6.TP, U1.2 (DO(IO1)), U2.27 (IO2)
MOSI: D11.2, J1.14, J4.P3 (CMD), R7.1, TP7.TP, U1.5 (DI(IO0)), U2.7 (IO7)
unnamed: C1_BAT1.1, D2.2 (CATHODE), IC4.1 (VIN), IC4.3 (CE), Q1.2 (S)
unnamed: C4.1, D3.2 (A), D4.1 (K)
unnamed: J2.B5, R2-USB.1
unnamed: MCP73831.1 (STAT), R1_BAT.2
unnamed: CHG_LED.C, R1_BAT.1
unnamed: MCP73831.5 (PROG), R2_BAT.2
unnamed: D7.2 (CATHODE), R_CAPACITOR.1
unnamed: J2.A5, R2-USB1.2
unnamed: EPD_C2.2, J1.5
unnamed: EPD_C1.2, J1.4
unnamed: D8.2, R10.1
unnamed: C_DELAY.1, IC1.5 (CT)
unnamed: EPD_C12.2, J1.24
unnamed: EPD_C6.2, J1.18
unnamed: EPD_C7.2, J1.19
unnamed: EPD_C10.2, J1.22
unnamed: EPD_C8.2, J1.20
PREVGH: D5.1 (K), EPD_C9.2, J1.21
PREVGL: D4.2 (A), EPD_C11.2, J1.23
RESE: J1.3, Q3.2 (S), R3.2
RESE': R2.2, R3.1, SJ1.2
RESET: C5.1, IC1.1 (VOUT), RESET_BUTTON.3, RESET_BUTTON.4, R_RESET.1, U2.3 (EN)
RTC_RST: U2.16 (IO18), U3.4 (!RST)
RX: TP2.TP, U2.24 (RXD0/GPIO17)
SCK: D10.2, J1.13, J4.P5 (CLK), R6.1, TP8.TP, U2.6 (IO6)
SCL: J3.4, R2-PINH.1, SENSOR2.4 (SCK), U2.20 (IO22), U3.16 (SCL), U4.7 (SCL)
SDA: J3.3, R1-PINH.1, SENSOR2.3 (SDI), U2.19 (IO21), U3.15 (SDA), U4.8 (SDA)
SRC: C4.2, D5.2 (A), L1.1, Q3.3 (D)
SS_SD: J4.P2 (CD/DAT3), U1.6 (CLK), U2.4 (IO4)
TX: TP1.TP, U2.25 (TXD0/GPIO16)
USB_D+: D1.4 (I/O2_2), U2.14 (IO13)
USB_D-: D1.6 (I/O1_2), U2.13 (IO12)
VBAT: C2_BAT.2, MCP73831.3 (VBAT), Q1.3 (D), TP3.TP, U4.2 (CELL), U4.3 (VDD)
VBUS: C1_BAT.1, C4_USB.1, C5_USB.1, CHG_LED.A, D1.2 (GND), D2.1 (ANODE), MCP73831.4 (VIN), PFMF.050.14.2, Q1.1 (G), R1_PWRUSB.2, TP14.TP
VRTC: C8.1, C10_SUPERCAP.2, R_CAPACITOR.2, U3.14 (VBAT)
VUSB: J2.A4, J2.A9, J2.B4, J2.B9, PFMF.050.14.1

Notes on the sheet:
SD Card
USB C connector & ESD protection
LDO Voltage Regulator
Display Type Selector
E-Paper Drive Circuit
Li-Po Battery Charging Controller
ESP32 C6
E-Paper Display Header
EPD Power
Environmental Sensor BME688
Voltage Supervisor + Reset & Boot / IO Button
Battery Charge Level
RTC Module DS3231SN
Test Pads
Qwiic / Stemma QT
SPI ESD Protection Lines
External NOR Flash 64MB
Andrei Cret - 335CA

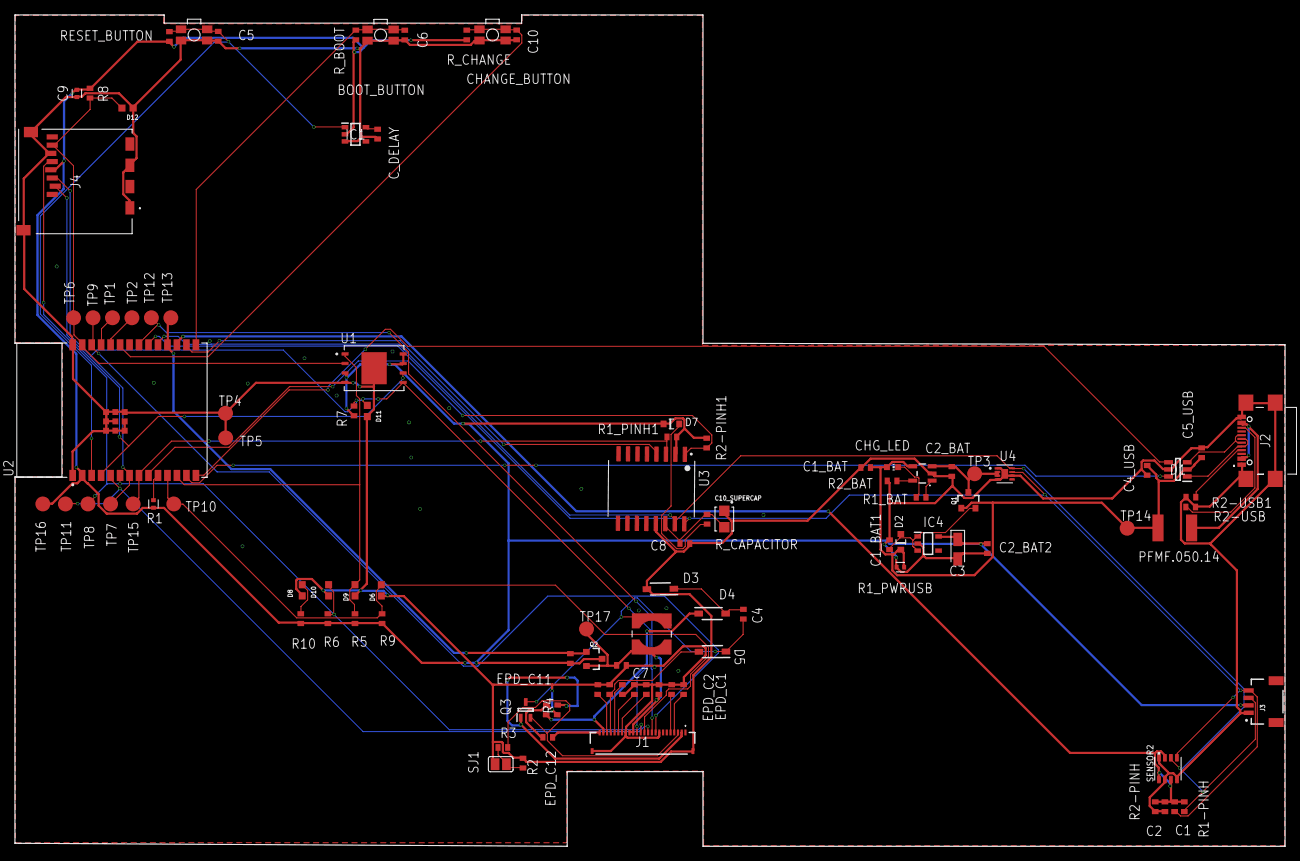
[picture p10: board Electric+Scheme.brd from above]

Board: 2 copper layers, 170.2 x 111.4 mm, 103 parts (0 on the bottom side), 56 nets.

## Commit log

2025-04-14 Add files via upload
    Updated pcb, rerouted and moved labels.
    [Electric+Scheme.brd]
2025-04-15 Update plan de masa.
    [Electric+Scheme.brd]

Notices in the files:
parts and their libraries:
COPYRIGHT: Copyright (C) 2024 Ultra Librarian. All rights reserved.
